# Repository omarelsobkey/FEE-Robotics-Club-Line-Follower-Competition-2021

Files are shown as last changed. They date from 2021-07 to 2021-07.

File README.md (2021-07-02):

# Robotics FEE Line Follower Competition Competition 2021  
### This robot (Zaghlol) was designed and assembled with contribution of:
Asmaa Salim - Salma Bakr - Mohamed Elfar - Ahmed Ashraf - Omar Elsobkey

### Robot Parts:
* 3 IR Sensors were made using TCRT5000 with LM358 OP-AMP for analog to digital output conversion. These sensors are for line detecting.
* Motor Driver Circuit using L293D to control both the speed and direction of the motors.
* Power ditribution circuit that outputs 12, 5 VDC to power the arduino, the motors and the sensors with three LM7805 connected in parallel in order to have high output ampere.
* Arduino Uno R3 to control the whole functionality of the robot

### Used Softwares:
* Arduino IDE for Arduino Code
* Altium and EAGLE for PCB Design
* Fusion360 for EAGLE's PCB 3D modeling
* Proteus For Simulation

### This repo includes:
* PCB files
* Arduino Code
* Robot presentation
* 3D modeling of the assembled robot

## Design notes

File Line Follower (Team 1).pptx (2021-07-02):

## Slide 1

- Team 1

- Line Follower Robot

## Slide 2

- Line Follower Robot

Microcontroller

Arduino

Power

Power Distribution

IR sensor

Signal sensor

Motor driver

Movement controller

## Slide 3

- L293D Motor Driver

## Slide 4

- L293D Motor Driver

- Pins Diagram

Enable 1,2
Controlling Motor 1 Speed
Input 1, Input 2
Controlling Motor 1 Direction
Output 1, Output 2
Connected to the controlled
motor
Vcc2
The voltage required for
the motors to work
4.5V:36V

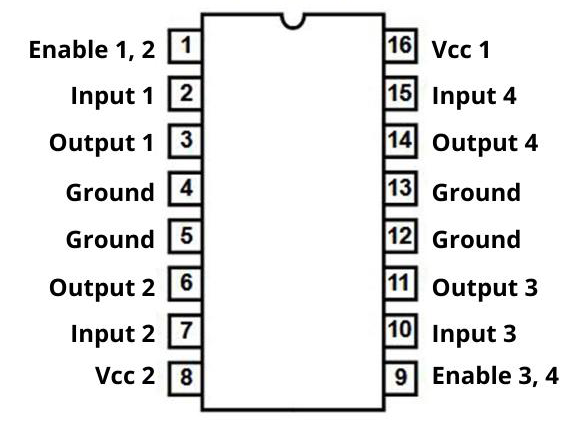
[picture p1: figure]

Enable 3,4
Controlling Motor 2 Speed
Input 3, Input 4
Controlling Motor 2 Direction
Output 1, Output 2
Connected to the controlled
motor
Vcc1
5V for internal logic translation

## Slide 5

- L293D Motor Driver

- PCB

Motor #2 Controlling Data
In3, in4 -> direction
ENB -> speed

Controlled Motor #2

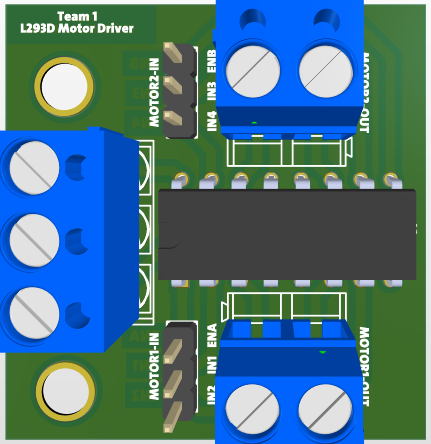
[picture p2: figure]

Fastening Holes

Power for circuit’s
Components
+5V, 0V, +12V

Motor #1 Controlling Data
In1, in2 -> direction
ENA -> speed

L293D IC

Controlled Motor #1

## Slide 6

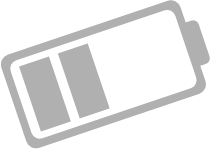
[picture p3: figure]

- IR Sensor

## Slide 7

TCRT5000 Sensor

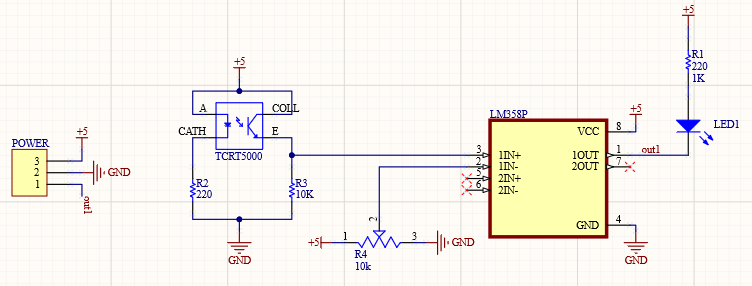
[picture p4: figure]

Schematic circuit of TCRT5000

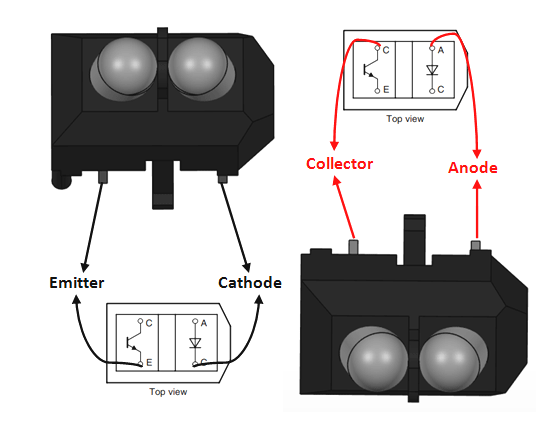
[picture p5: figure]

TCRT5000 sensor

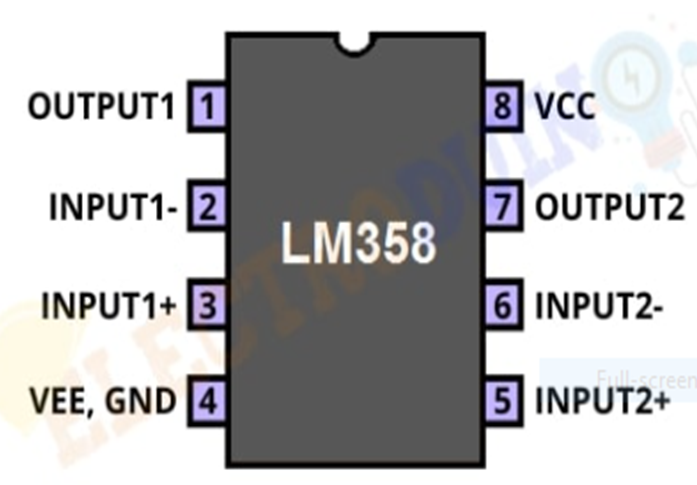
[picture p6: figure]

LM358 OP-amp

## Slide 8

PCB

Top layer

- Pin header

Bottom layer

LM358

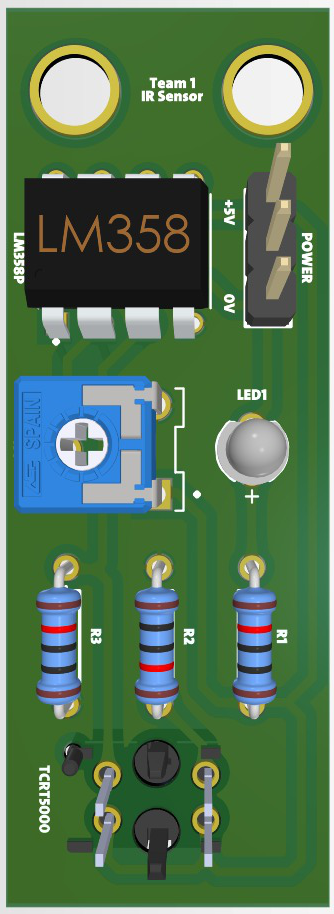
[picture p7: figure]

led1

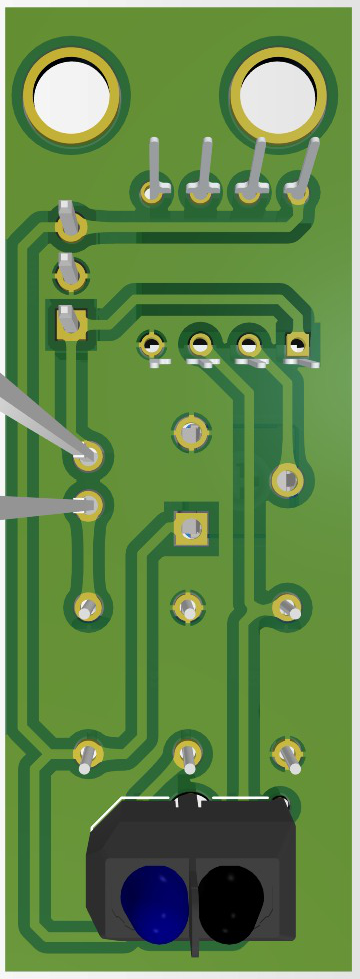
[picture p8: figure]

V-R

R3

R1

- Tcrt5000

R2

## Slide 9

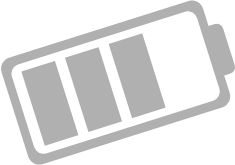
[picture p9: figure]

- Power Distribution

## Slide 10

- Power Distribution

Output 12V, 5V

On/Off Switch

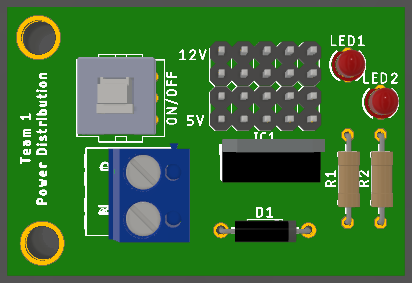
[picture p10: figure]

Distributes Batteries power in order to be able to operate all robot’s parts
with the same battery

Output Indicating
LEDs

V-Reg 7805

Fastening Holes

Input 12V

Prevent Wrong
Connection

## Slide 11

- Arduino Code

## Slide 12

Arduino UNO

Maximum input current 20mA

Maximum output current
40mA

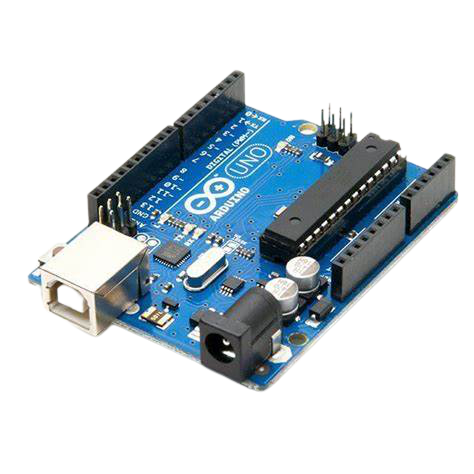
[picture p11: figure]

Microcontroller ATmega328

14 Digital I/O pins
(of which 6 provide PWM output)

6 analog input pins

Operating volte 5V

Input voltage
(recommended) 7-12V

Input voltage (limits) 6-20V

Three power ways

Clock speed 16MHz

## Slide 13

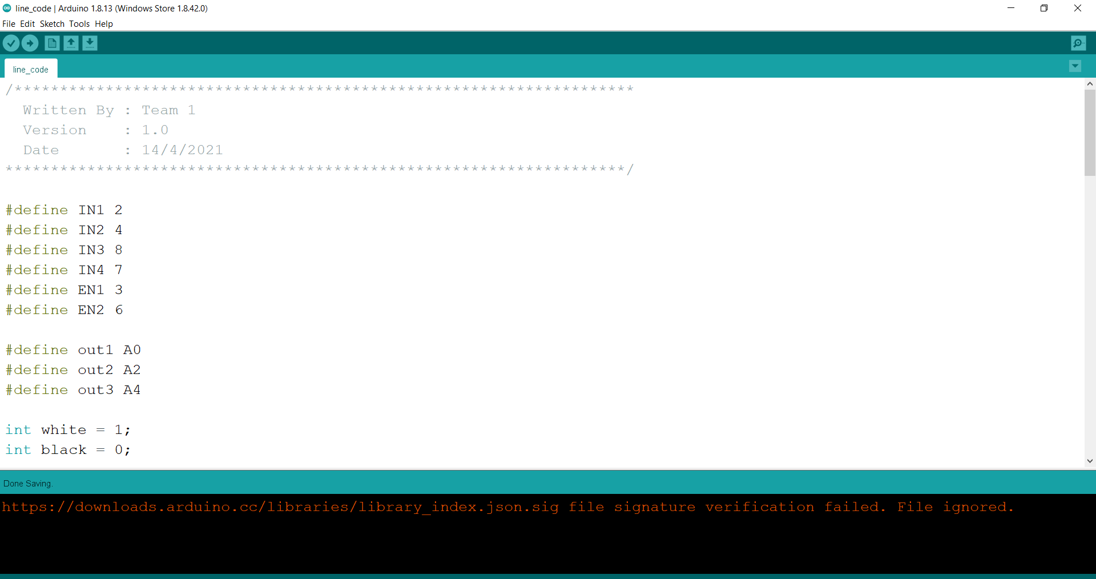
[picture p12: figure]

Showing motors pins, sensors pins and define them

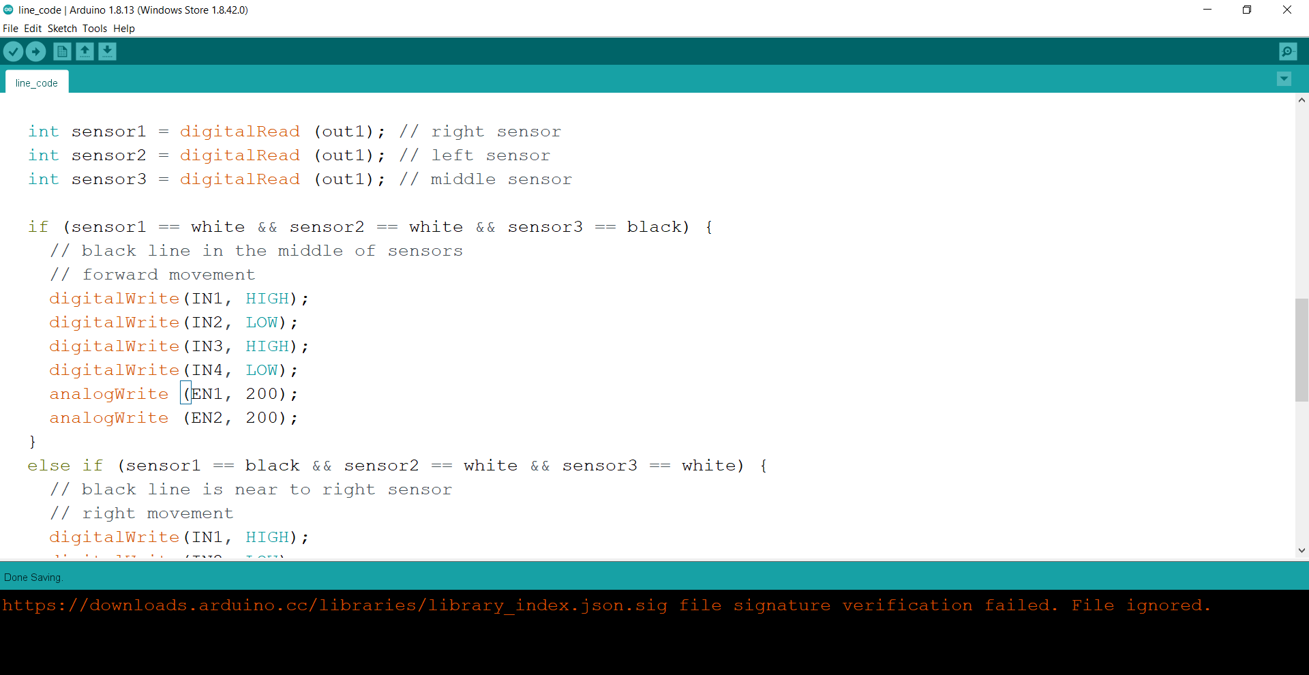
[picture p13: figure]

Movement functions
( showing how to control robot movement )

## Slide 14

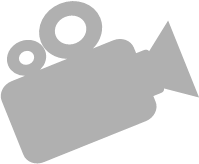
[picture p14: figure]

Final Result

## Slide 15

Simulation schematic circuit

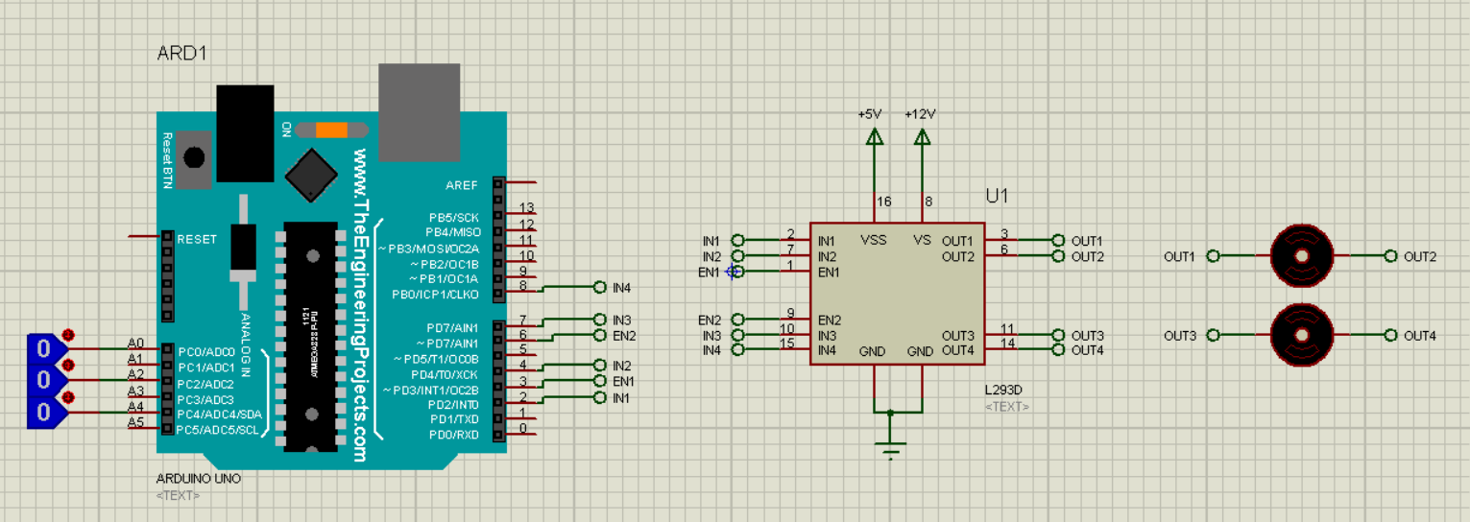
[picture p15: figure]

Due to error in the downloaded sensor's library we replaced it in the simulation with logic states

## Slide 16

Robot chassis

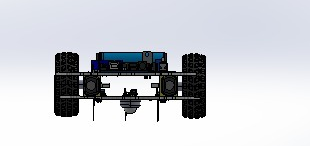
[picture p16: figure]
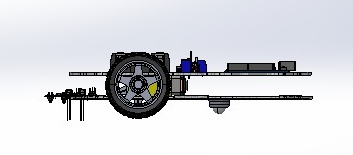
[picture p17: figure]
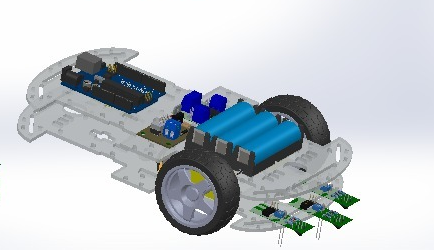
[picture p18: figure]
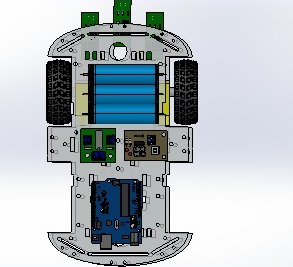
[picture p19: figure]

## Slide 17

- Thank you

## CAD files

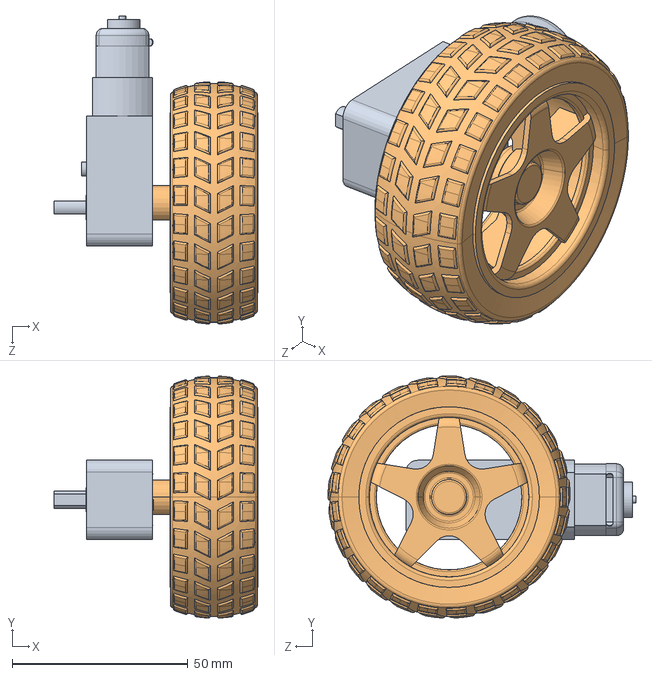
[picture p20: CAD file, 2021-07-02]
3D/Motor and Wheel.SLDASM
58.0 x 68.9 x 87.6 mm
Motor
Wheel

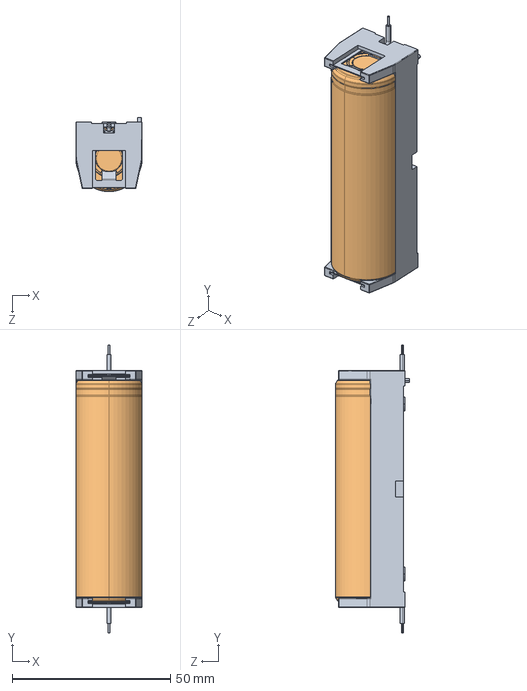
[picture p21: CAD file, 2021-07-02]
3D/Power.SLDASM
21.0 x 91.0 x 23.5 mm
Battery Holder.stp
Battery

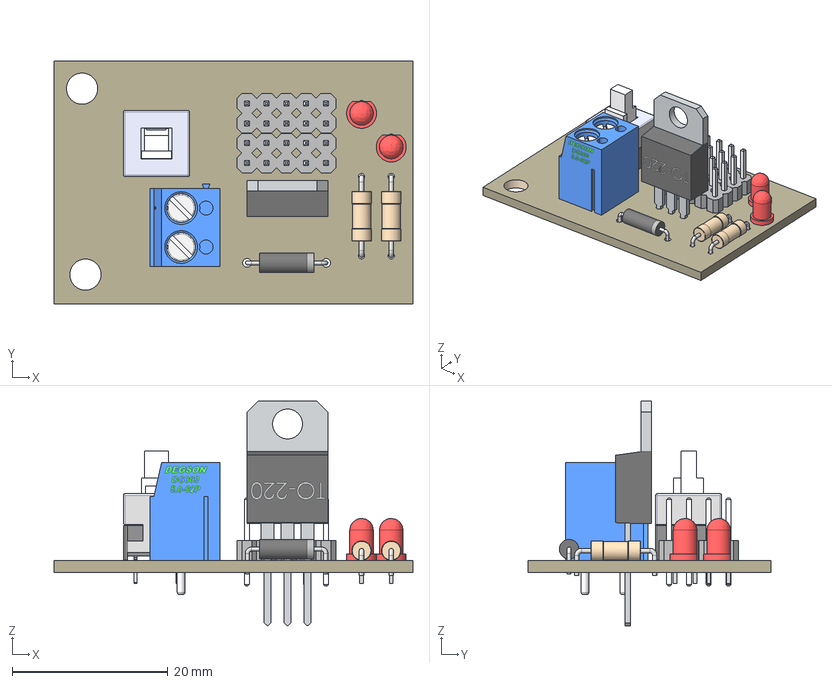
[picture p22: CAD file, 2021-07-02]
3D/Power Distribution.step
46.1 x 31.2 x 28.9 mm
Board
2X05 x 2
1N4004
LEDBody x 2
Lead1Body x 2
Lead2Body x 2
PVA2R
AK500/2-H

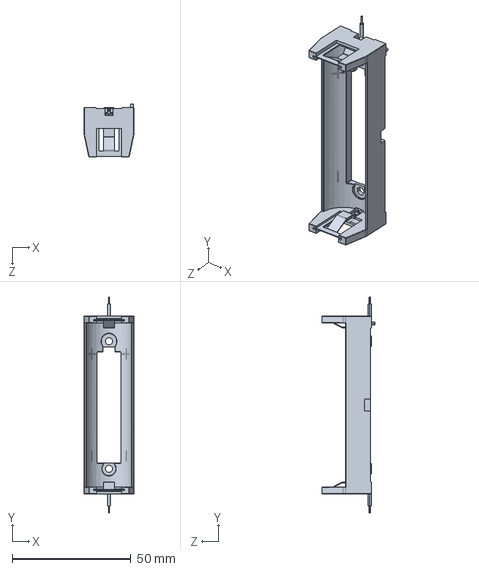
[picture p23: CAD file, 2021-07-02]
3D/Battery Holder.stp.SLDPRT
21.0 x 91.0 x 22.5 mm

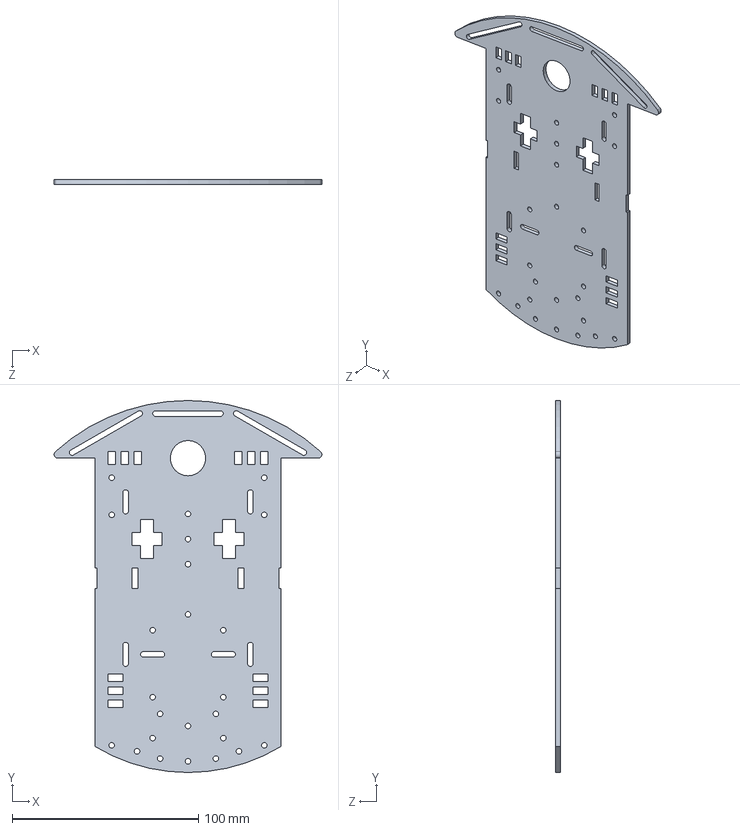
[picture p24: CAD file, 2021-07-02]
3D/2WD Chassis.SLDPRT
144.0 x 200.0 x 2.50 mm

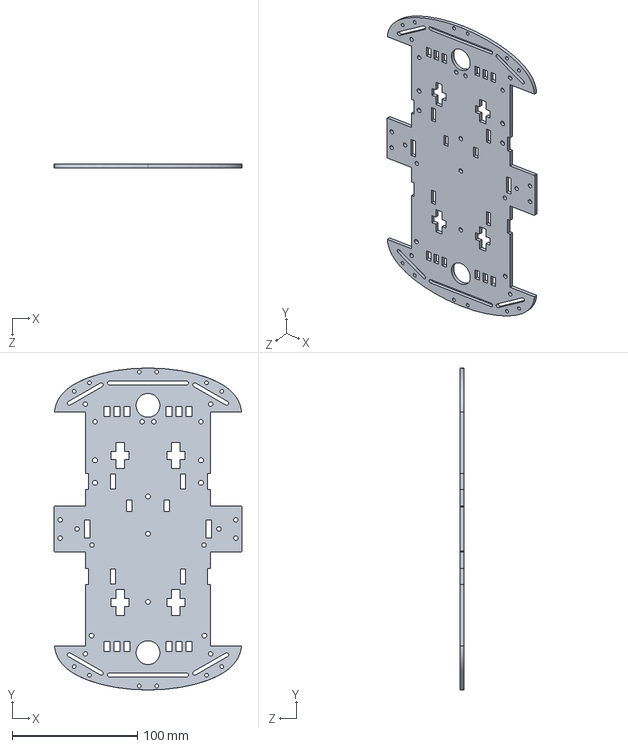
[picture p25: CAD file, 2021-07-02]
3D/4WD Chassis.STEP
150.0 x 257.0 x 3.00 mm

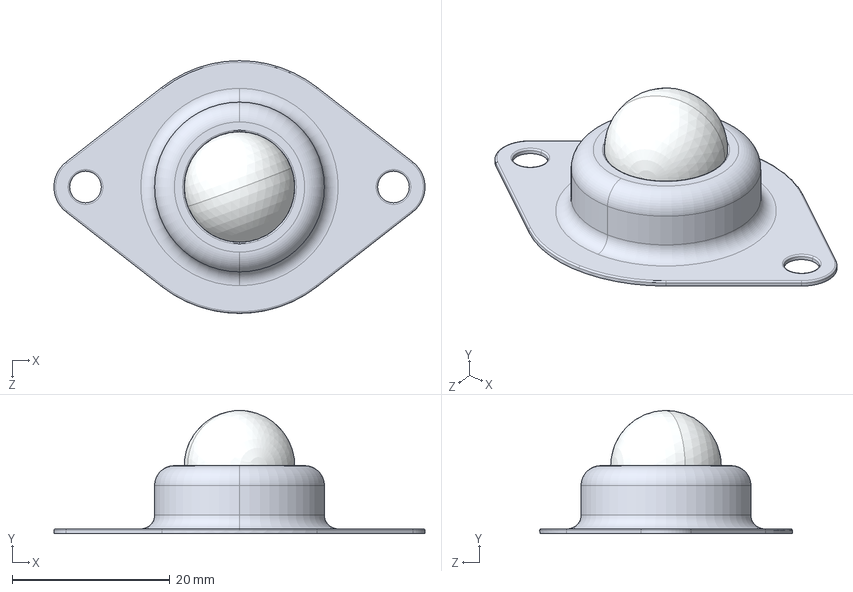
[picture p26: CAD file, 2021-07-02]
3D/Caster Ball Wheel.STEP
47.0 x 15.6 x 32.0 mm
Wheel''s Body
Ball

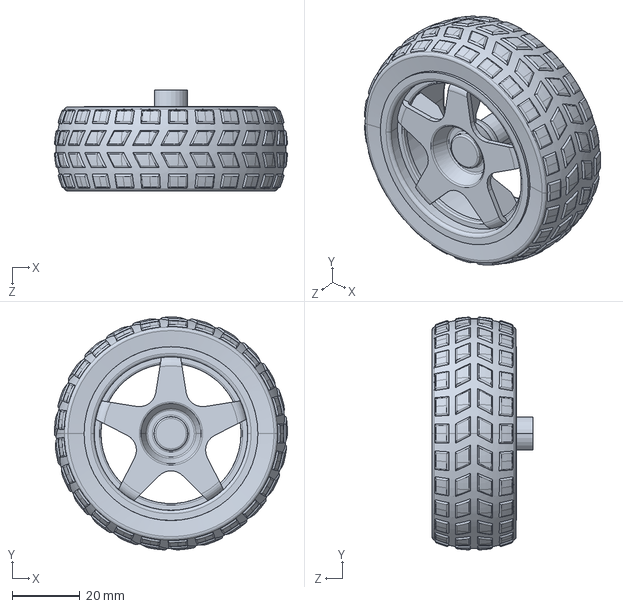
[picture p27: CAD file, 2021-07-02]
3D/Wheel.SLDPRT
68.9 x 68.9 x 30.0 mm

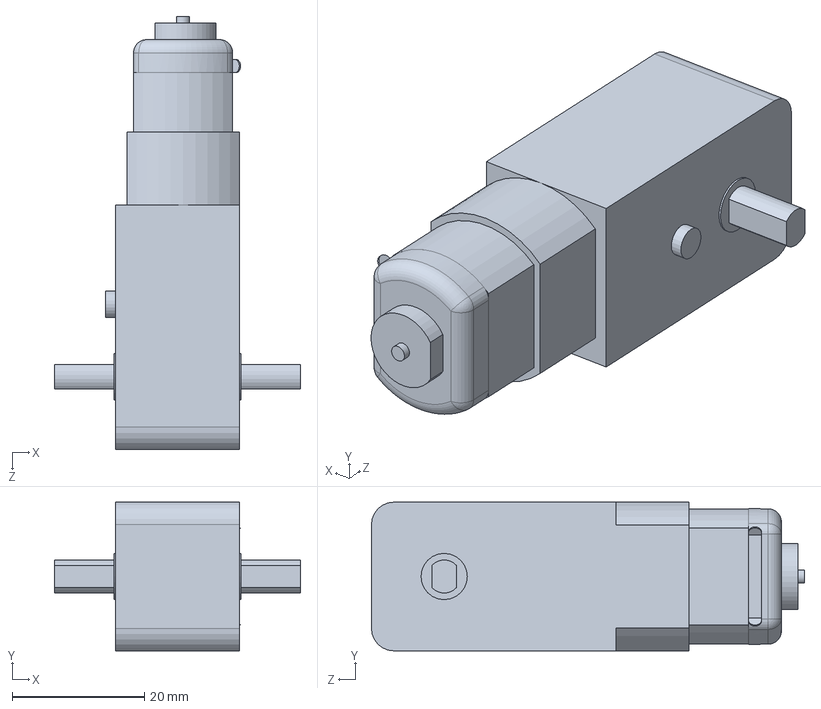
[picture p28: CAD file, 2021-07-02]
3D/Motor.SLDPRT
37.2 x 22.5 x 65.5 mm

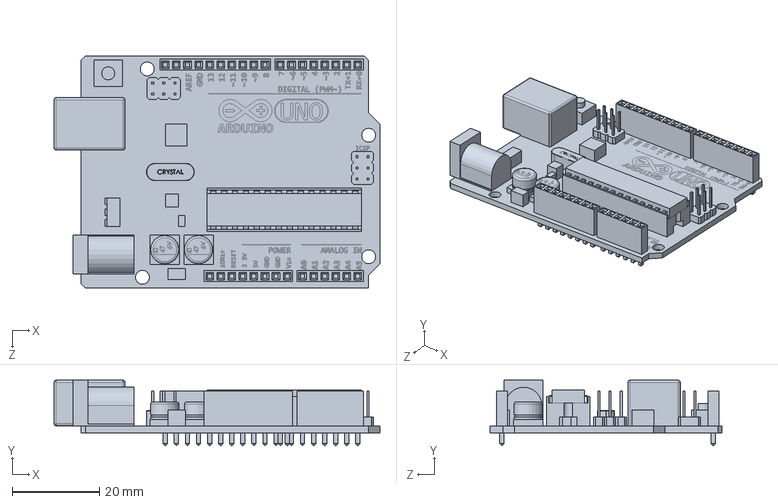
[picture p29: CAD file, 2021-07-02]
3D/Arduino.SLDPRT
74.8 x 15.1 x 53.3 mm

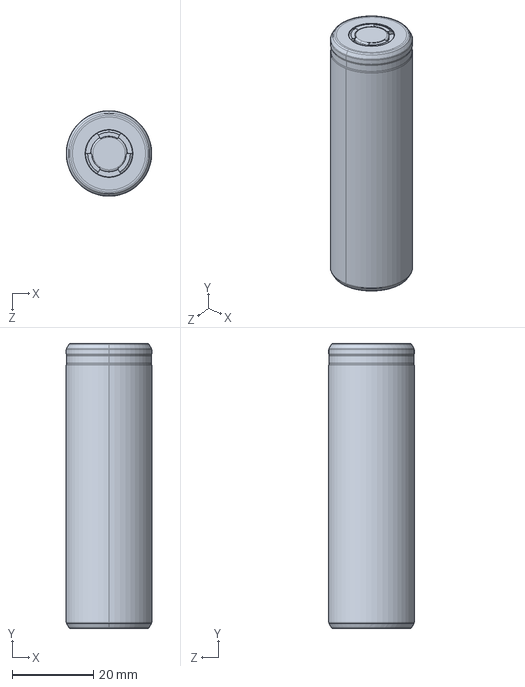
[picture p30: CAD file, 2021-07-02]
3D/Battery.SLDPRT
21.0 x 70.0 x 21.0 mm

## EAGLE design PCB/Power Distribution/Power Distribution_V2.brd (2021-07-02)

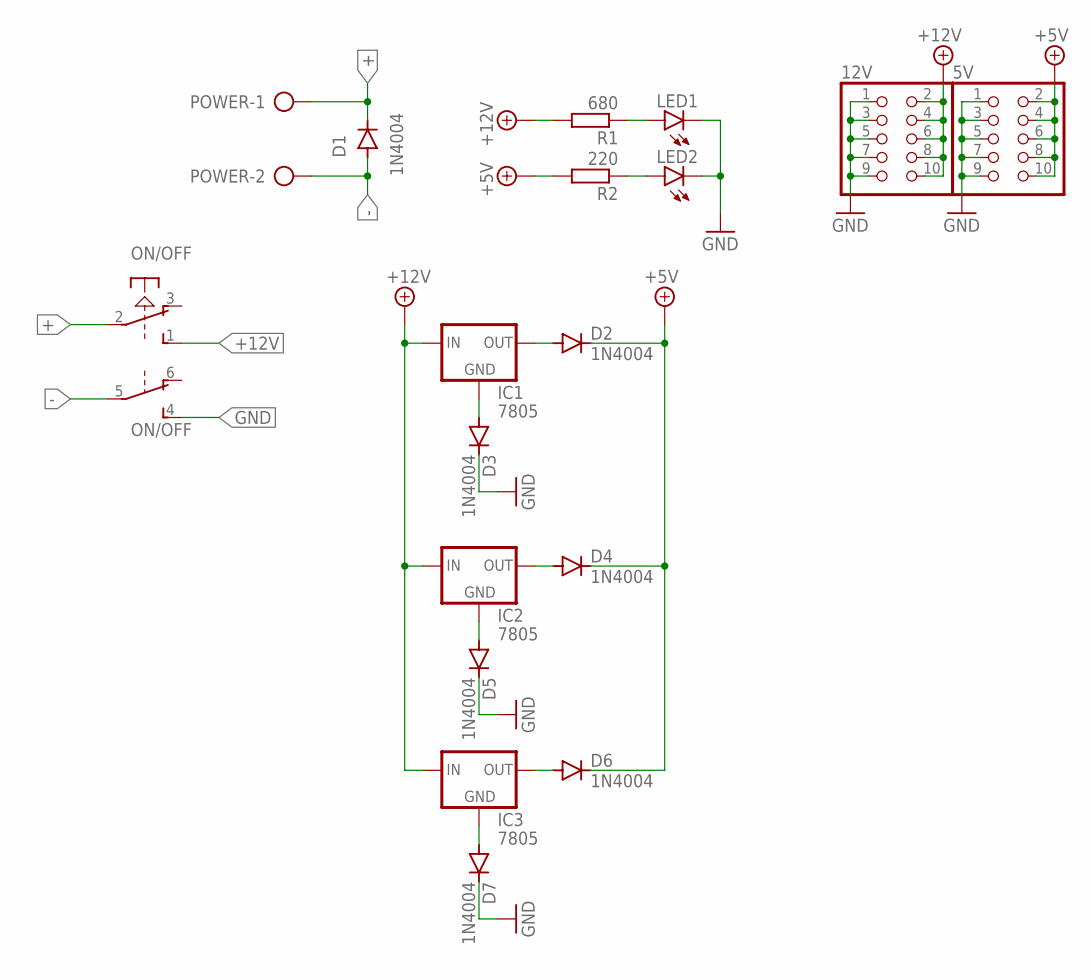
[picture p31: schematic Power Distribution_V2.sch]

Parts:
5V, 12V: PINHD-2X5; 2X05
D1, D2, D3, D4, D5, D6, D7: 1N4004; DO41-10
IC1, IC2, IC3: 7805; 78XXS
LED1, LED2: LED3MM
ON/OFF: PVA2R
POWER: AK500/2-H
R1: 680; 0207/10
R2: 220; 0207/10

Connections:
+: D1.C, ON/OFF.2, POWER.1
+5V: 5V.2, 5V.4, 5V.6, 5V.8, 5V.10, D2.C, D4.C, D6.C, R2.2
+12V: 12V.2, 12V.4, 12V.6, 12V.8, 12V.10, IC1.IN, IC2.IN, IC3.IN, ON/OFF.1 (S), R1.2
-: D1.A, ON/OFF.5, POWER.2
GND: 5V.1, 5V.3, 5V.5, 5V.7, 5V.9, 12V.1, 12V.3, 12V.5, 12V.7, 12V.9, D3.C, D5.C, D7.C, LED1.K (C), LED2.K (C), ON/OFF.4 (S)
unnamed: LED1.A, R1.1
unnamed: D7.A, IC3.GND
unnamed: LED2.A, R2.1
unnamed: D5.A, IC2.GND
unnamed: D3.A, IC1.GND
unnamed: D2.A, IC1.OUT
unnamed: D6.A, IC3.OUT
unnamed: D4.A, IC2.OUT

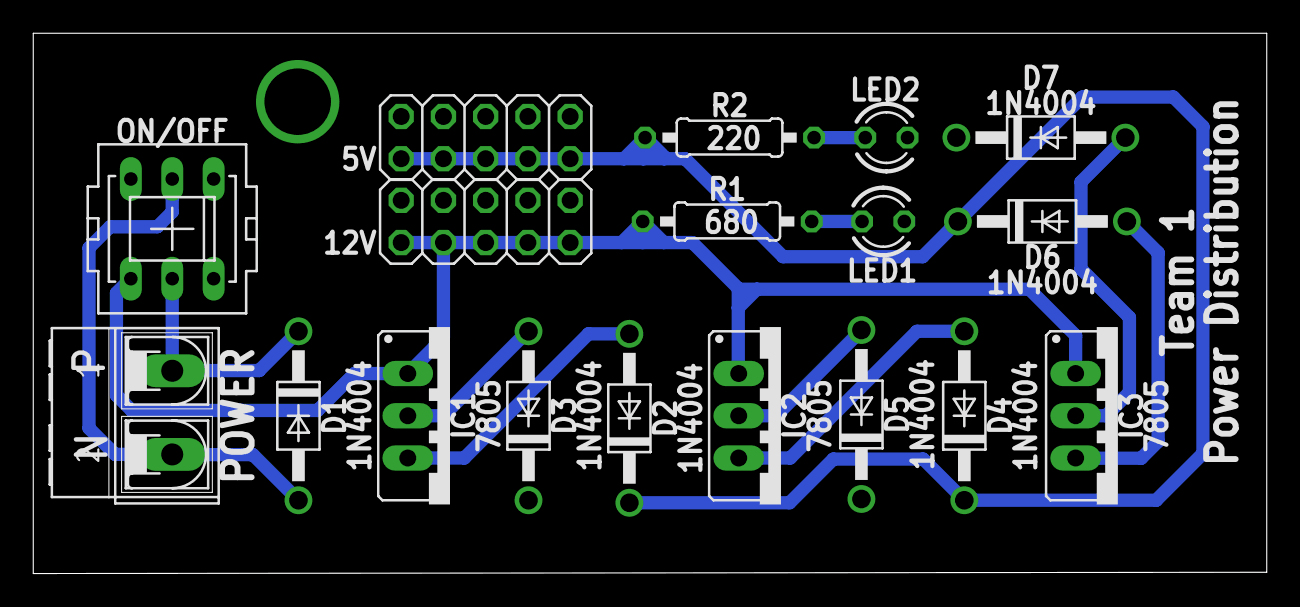
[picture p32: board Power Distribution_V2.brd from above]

Board: 2 copper layers, 74.2 x 32.5 mm, 18 parts (0 on the bottom side), 13 nets.

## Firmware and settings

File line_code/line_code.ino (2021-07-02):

//left motor dirction and speed
#define IN1 5
#define IN2 8
#define EN1 9

//right motor dirction and speed
#define IN3 7
#define IN4 10
#define EN2 6

// sensors' signals' pins
#define signal1 2//right sensor
#define signal2 3//middel sensor
#define signal3 4//left sensor

//signals values
int white = 1;
int black = 0;
void setup() {
  // put your setup code here, to run once:
  pinMode (IN1, OUTPUT);
  pinMode (IN2, OUTPUT);
  //  pinMode (EN1, OUTPUT);

  pinMode (IN3, OUTPUT);
  pinMode (IN4, OUTPUT);
  //  pinMode (EN2, OUTPUT);

  pinMode (signal1, INPUT);
  pinMode (signal2, INPUT);
  pinMode (signal3, INPUT);

//  Serial.begin(9600);
}
void motor ( int LM, int RM)
{
  // control left motor directions and speed
  if ( LM < 0)
  {
    digitalWrite(IN1, LOW);
    digitalWrite(IN2, HIGH);
    analogWrite (EN1, -LM);

  }
  if (LM > 0)
  {
    digitalWrite(IN1, HIGH);
    digitalWrite(IN2, LOW);
    analogWrite (EN1, LM);
  }
  if (LM == 0)
  {
    digitalWrite(IN1, LOW);
    digitalWrite(IN2, LOW);
    analogWrite (EN1, 0);
  }

  // control right motor directions and speed
  if (RM < 0)
  {
    digitalWrite(IN3, HIGH);
    digitalWrite(IN4, LOW);
    analogWrite (EN2, -RM);
  }

  if (RM > 0)
  {
    digitalWrite(IN3, LOW);
    digitalWrite(IN4, HIGH);
    analogWrite (EN2, RM);
  }

  if (RM == 0)
  {
    digitalWrite(IN3, LOW);
    digitalWrite(IN4, LOW);
    analogWrite (EN2, 0);
  }
}
void loop() {
  // put your main code here, to run repeatedly:
  int s1 = digitalRead (signal1);//right sensor
  int s2 = digitalRead (signal2);//middel sensor
  int s3 = digitalRead (signal3);//left sensor
//
//  Serial.print(s1);
//  Serial.print(s2);
//  Serial.println(s3);
  if (s1 == black && s2 == black && s3 == black)
  {
    delay(100);
    motor(0, 0);
}
if (s1 == white && s2 == black && s3 == black)
  {
    motor(110, -110);
  }
  //middel sensor
  if (s2 == black && s1 == white && s3 == white)
  {
    motor(120, 120);
  }
  // left sensor
  if (s3 == black && s2 == white && s1 == white )
  {
    motor(-130, 130);
  }
  //right sensor
  if (s1 == black && s2 == white && s3 == white)
  {
    motor(130,-130);
  }
}

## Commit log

2021-07-02 Upload all the project data
    [2WD Chassis.SLDPRT, 4WD Chassis.STEP, Arduino.SLDPRT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]
2021-07-02 add the remaining files.
    [Motor and Wheel.SLDASM, Motor.SLDPRT, Power Distribution.step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]
